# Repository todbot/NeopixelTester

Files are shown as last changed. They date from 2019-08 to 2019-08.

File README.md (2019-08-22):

# NeopixelTester

Some testing hardware for Neopixels (WS2812, SK6812)

In this repo:
- boards - schematic in Eagle format
- sketches - Sketches to run on Trinket M0

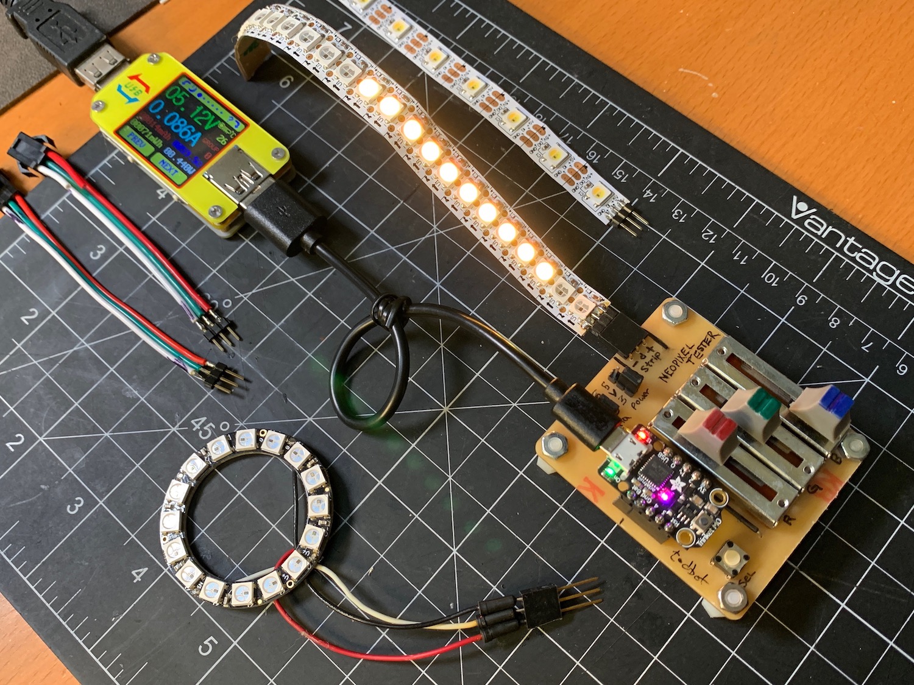
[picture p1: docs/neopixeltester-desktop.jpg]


## Video of how it works
Click the pic to watch the video
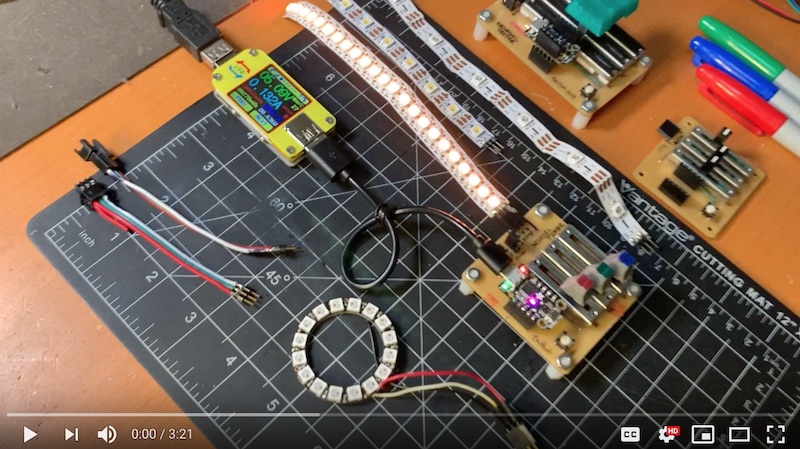
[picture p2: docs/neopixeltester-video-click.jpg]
Watch the video (https://youtu.be/KODPj4VacQQ)


## PCBs

Boards available on OSHPark:
https://oshpark.com/shared_projects/BqFE6DLx

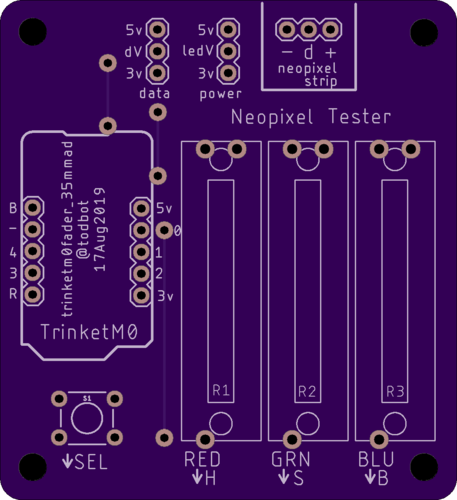
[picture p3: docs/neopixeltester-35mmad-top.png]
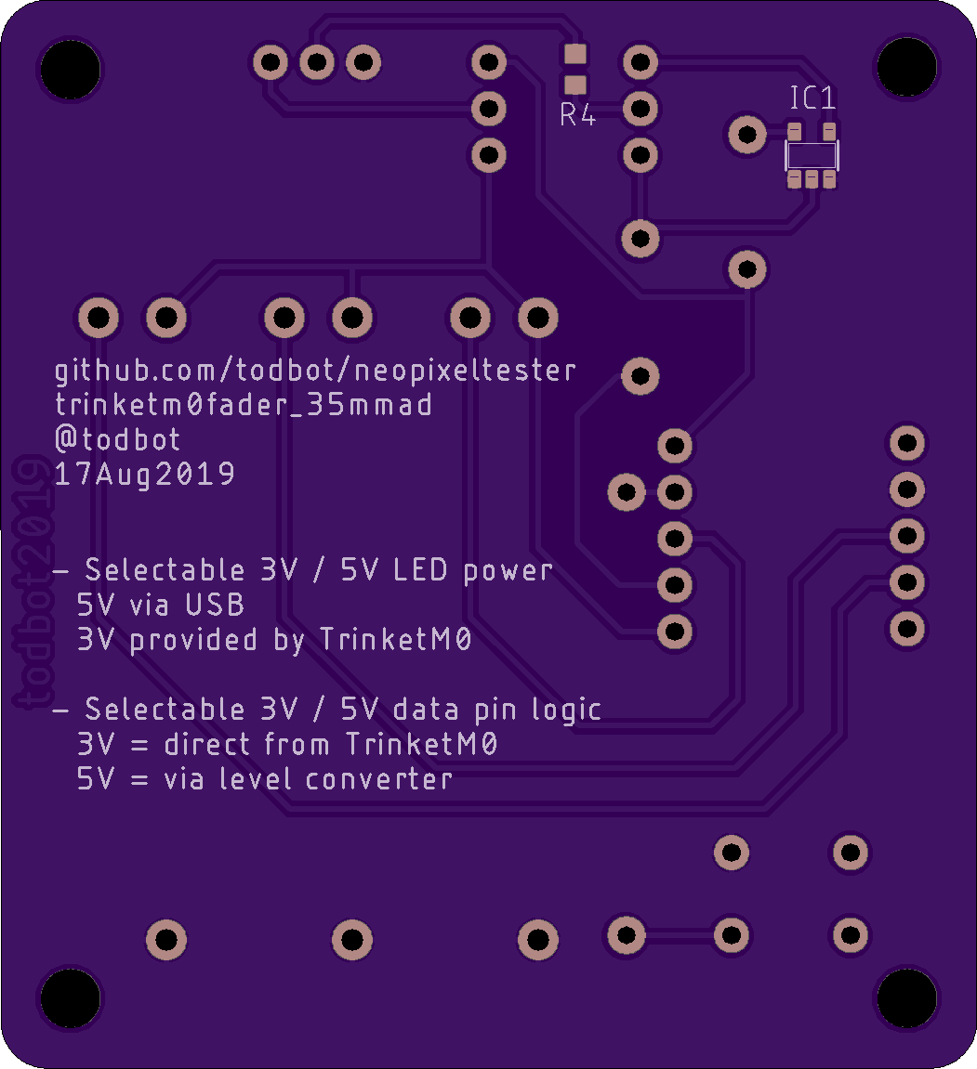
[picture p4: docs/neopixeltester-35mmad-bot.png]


Or you can mill your own with an Othermill/Bantam tools PCB mill. The board is designed to be single-sided milled with only three straight jumpers.

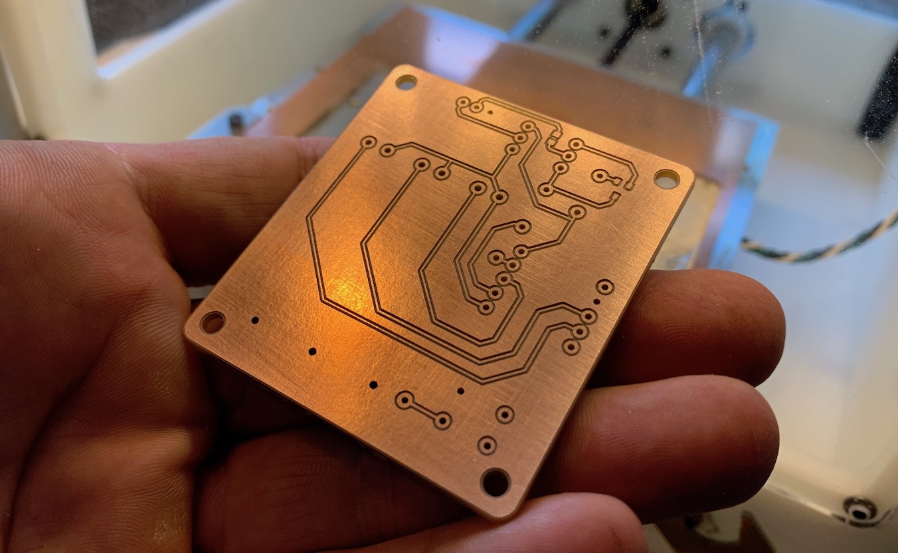
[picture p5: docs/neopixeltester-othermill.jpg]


## Bill of Materials
Bill of materials:
- Adafruit Trinket M0
- Adafruit 35mm slide pots x 3
- 74AHCT1G125DBV or SN74LV1T125DCKR level-shifter in SOT23-5 package
- 500 ohm resistor in 0603 package
- tact switch button
- male header pins, cut to length
- female header sockets, cut to length

Or if you're interested in the [60mm Amazon faders](http://amzn.com/B07PNDLKQQ?tag=todbotblog-20) on the other board.
And here's the [USB power meter](http://amzn.com/B07DK6FT4Q?tag=todbotblog-20) I showed in the video.

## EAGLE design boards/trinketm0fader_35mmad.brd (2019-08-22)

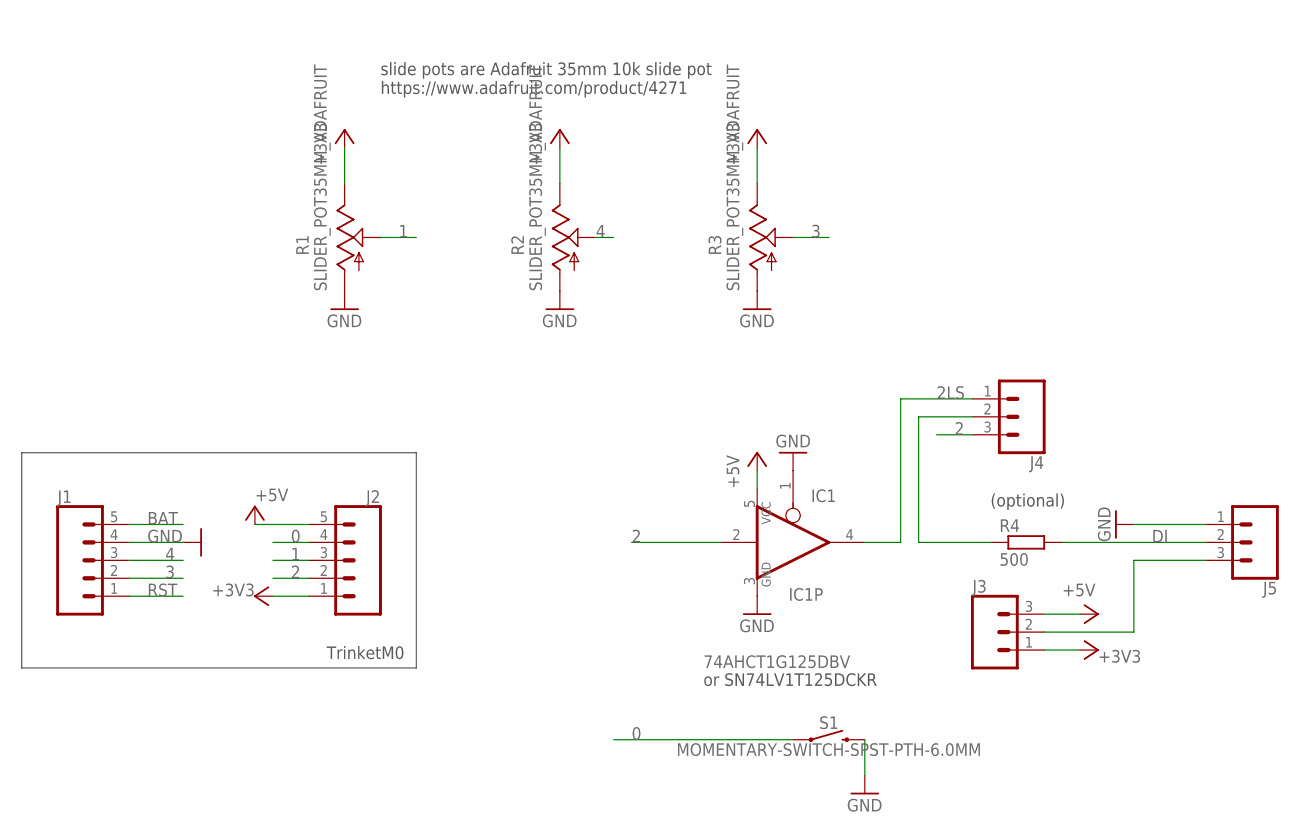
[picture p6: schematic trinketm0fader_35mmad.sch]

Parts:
IC1: 74AHCT1G125DBV; SOT23-5
J1, J2: CONN_05; 1X05
J3, J4, J5: CONN_03; 1X03
R1, R2, R3: SLIDER_POT35MM_ADAFRUIT; SLIDEPOD_35MM_ADAFRUIT
R4: 500; R0603
S1: MOMENTARY-SWITCH-SPST-PTH-6.0MM; TACTILE_SWITCH_PTH_6.0MM

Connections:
0: J2.4, S1.1
1: J2.3, R1.P$2 (W)
2: IC1.2 (I), J2.2, J4.3
2LS: IC1.4 (O), J4.1
3: J1.2, R3.P$2 (W)
4: J1.3, R2.P$2 (W)
+3V3: J2.1, J3.1, R1.P$1 (V), R2.P$1 (V), R3.P$1 (V)
+5V: IC1.5 (VCC), J2.5, J3.3
BAT: J1.5
DI: J5.2, R4.2
GND: IC1.1 (OE), IC1.3 (GND), J1.4, J5.1, R1.P$3 (G), R2.P$3 (G), R3.P$3 (G), S1.3 (2)
unnamed: J3.2, J5.3
unnamed: J4.2, R4.1
RST: J1.1

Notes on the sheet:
(optional)
TrinketM0
slide pots are Adafruit 35mm 10k slide pot https://www.adafruit.com/product/4271
or SN74LV1T125DCKR

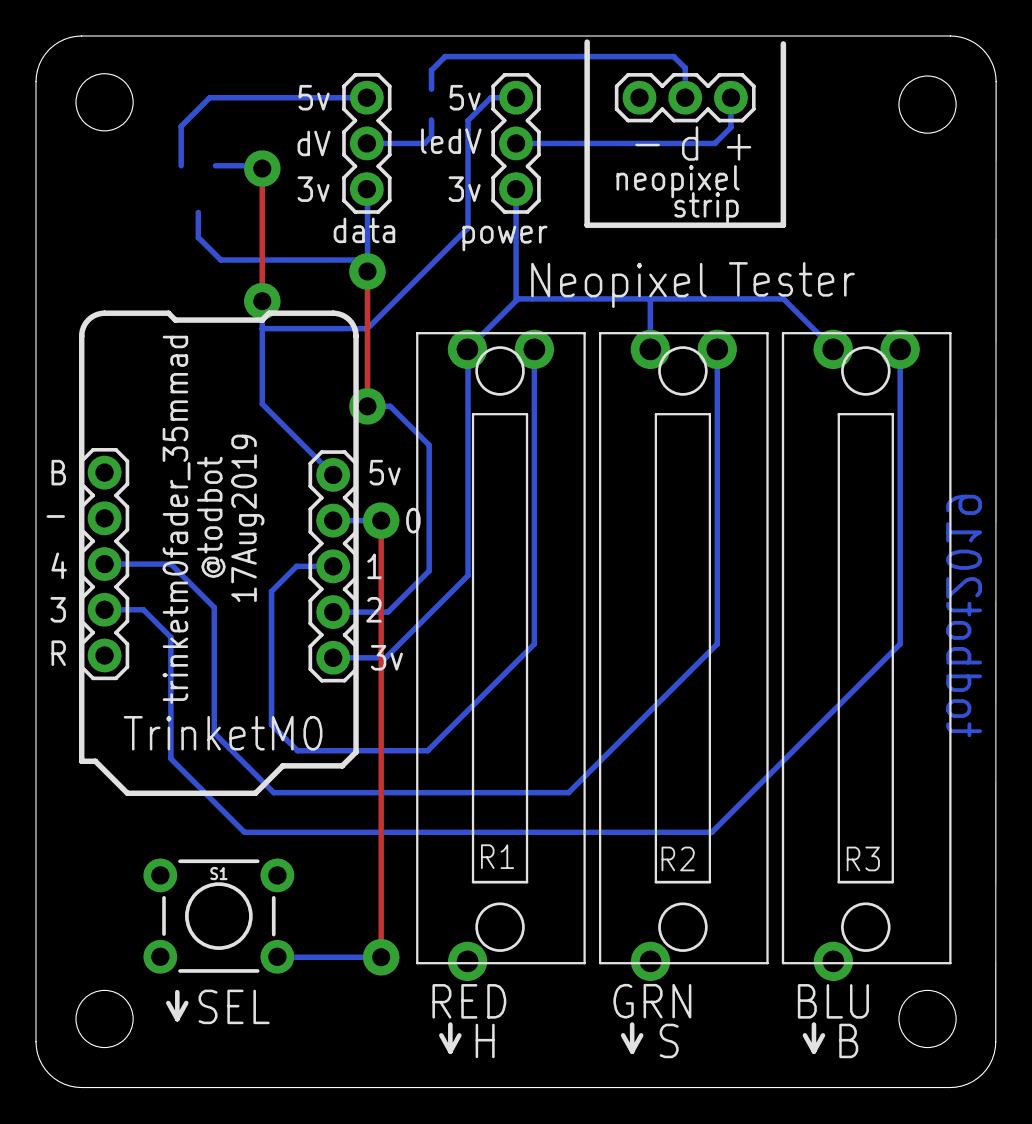
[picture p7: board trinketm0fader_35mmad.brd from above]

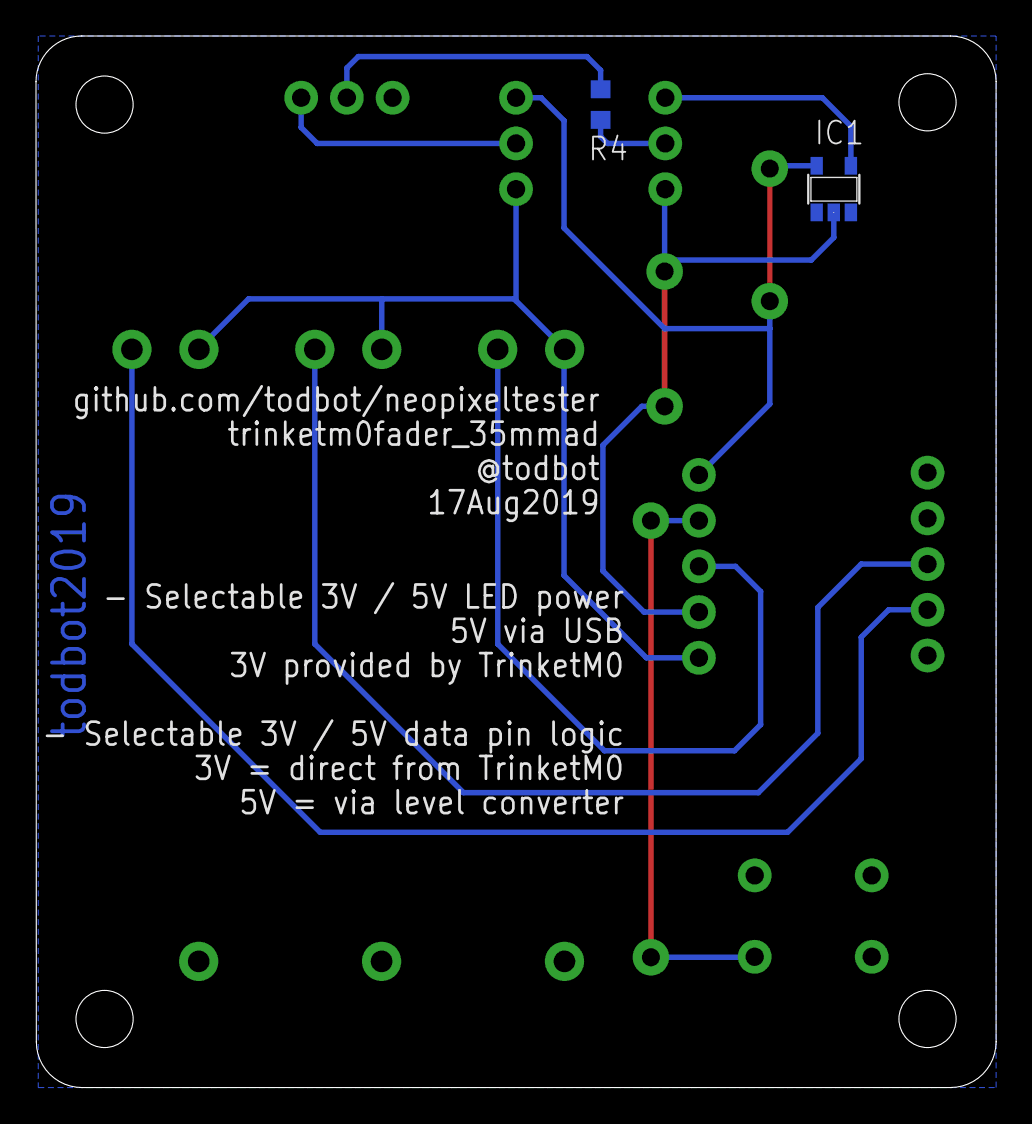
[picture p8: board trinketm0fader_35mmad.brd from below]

Board: 2 copper layers, 53.3 x 58.4 mm, 11 parts (2 on the bottom side), 12 nets.

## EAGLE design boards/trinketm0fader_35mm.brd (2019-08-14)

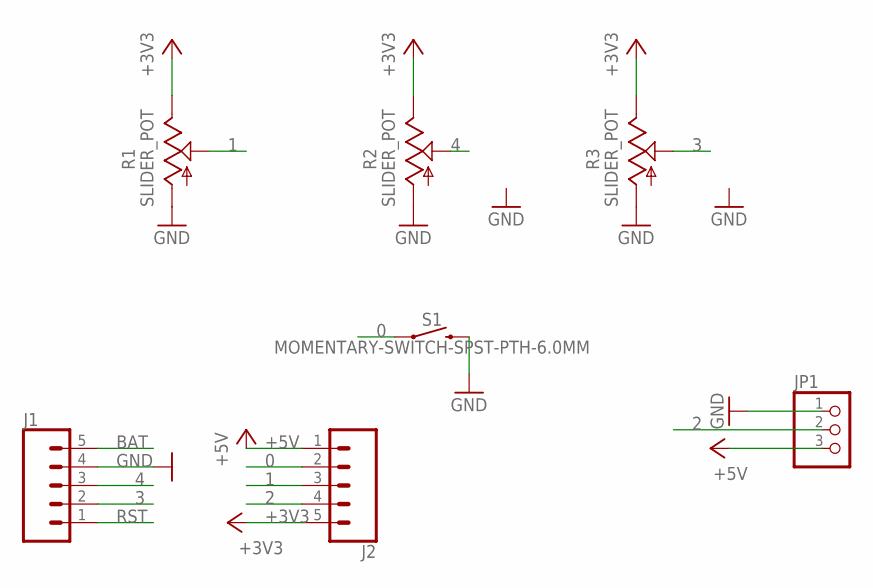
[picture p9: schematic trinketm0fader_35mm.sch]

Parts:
J1, J2: CONN_05; 1X05
JP1: PINHD-1X3; 1X03
R1, R2, R3: SLIDER_POT; SLIDEPOT_35MM_GUITAR
S1: MOMENTARY-SWITCH-SPST-PTH-6.0MM; TACTILE_SWITCH_PTH_6.0MM

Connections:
0: J2.2, S1.1
1: J2.3, R1.P$2 (S)
2: J2.4, JP1.2
3: J1.2, R3.P$2 (S)
4: J1.3, R2.P$2 (S)
+3V3: J2.5, R1.P$1 (E), R2.P$1 (E), R3.P$1 (E)
+5V: J2.1, JP1.3
BAT: J1.5
GND: J1.4, JP1.1, R1.P$4 (A), R2.P$4 (A), R3.P$4 (A), S1.3 (2)
RST: J1.1

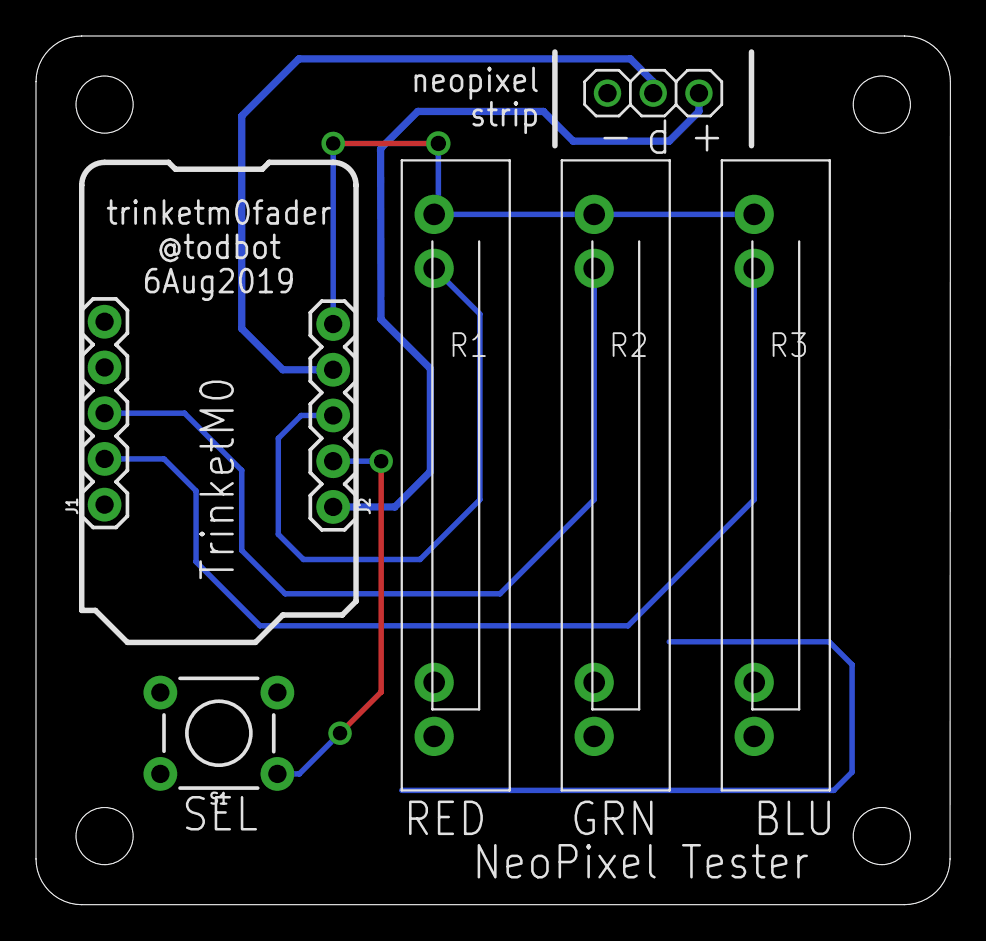
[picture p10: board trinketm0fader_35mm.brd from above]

Board: 2 copper layers, 50.8 x 48.3 mm, 7 parts (0 on the bottom side), 8 nets.

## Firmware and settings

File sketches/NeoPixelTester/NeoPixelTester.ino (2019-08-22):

/* NeoPixelTester 
 * ------------------- 
 * Simple Hello world for serial ports.
 * Print out "Hello world!" and blink pin 13 LED every second.
 *
 * Created 13 Aug 2019
 * 2019 Tod E. Kurt <tod@todbot.com>`http://todbot.com/
 */

#include <Adafruit_NeoPixel.h>
#include <Adafruit_DotStar.h>

//#define NUMPIXELS 16 // Popular NeoPixel ring size
#define NUMPIXELS 50 

// Pins in use
const int LED_PIN     = 13; // onboard LED
const int BUTT_PIN    = 0;  // D0 A2
const int NEO_PIN     = 2;  // D2 A1
const int SLIDER1_PIN = A0; // D1
const int SLIDER2_PIN = A4; // D4
const int SLIDER3_PIN = A3; // D3
const int DOTSTAR_DAT = 7; 
const int DOTSTAR_CLK = 8; 

Adafruit_DotStar dotstrip = Adafruit_DotStar( 1, DOTSTAR_DAT, DOTSTAR_CLK, DOTSTAR_BGR);

Adafruit_NeoPixel* pixels;

uint8_t r,g,b,w;
int startLed = 0;
int endLed = NUMPIXELS;
uint8_t brightness = 255;
uint32_t debugNextMillis;

bool rgbw_mode = false;

void setup() 
{
    dotstrip.begin(); // Initialize pins for output
    dotstrip.setPixelColor(0,0x003300);
    dotstrip.show();
    
    Serial.begin(115200);
    pinMode(LED_PIN, OUTPUT); 
    pinMode(SLIDER1_PIN, INPUT);
    pinMode(SLIDER2_PIN, INPUT);
    pinMode(SLIDER3_PIN, INPUT);
    pinMode(BUTT_PIN, INPUT_PULLUP);

    pixels = new Adafruit_NeoPixel(NUMPIXELS, NEO_PIN, NEO_GRB + NEO_KHZ800);
    pixels->begin();
    pixels->setBrightness(brightness);

    // set RGBW on startup
    if( digitalRead(BUTT_PIN) == LOW ) { 
        rgbw_mode = true;
        //pixels->updateType( NEO_RGBW );
        pixels = new Adafruit_NeoPixel(NUMPIXELS, NEO_PIN, NEO_GRBW + NEO_KHZ800);
    }
  
    // say hello
    for(int i=0; i<NUMPIXELS; i++) { 
        pixels->setPixelColor(i, pixels->Color(0, 150, 0));
        pixels->show();   // Send the updated pixel colors to the hardware.
        delay(30);
    }  
}

void loop () 
{
    digitalWrite(LED_PIN, HIGH);
    int v0 = digitalRead(BUTT_PIN);
    int v1 = analogRead(SLIDER1_PIN);
    int v2 = analogRead(SLIDER2_PIN);
    int v3 = analogRead(SLIDER3_PIN);
  
    // debug once every 100 millis
    if( debugNextMillis - millis() > 100 ) { 
        debugNextMillis = millis() + 100;
        Serial.printf("mode:rgb%c ins: %d, %d, %d, %d, st:%d end:%d bri:%d\n",
            (rgbw_mode?'w':' '), v0, v1,v2,v3, startLed, endLed, brightness);
    }
 
    if( v0 ) {  // normal mode: sliders are RGB
        dotstrip.setPixelColor(0,0x330033); // mode
        dotstrip.show();
        r = v1 / 4;
        g = v2 / 4;
        b = v3 / 4;
    }
    else {      // alt mode
        dotstrip.setPixelColor(0,0x333333);
        dotstrip.show();
        brightness = v3 / 4;
        startLed = map( v1, 0,1023, 0,NUMPIXELS-1);
        int numLeds = map( v2, 0,1023, 1,NUMPIXELS);
        endLed = startLed + numLeds;
        if( endLed > NUMPIXELS ) { 
            endLed = NUMPIXELS;       
        }
        pixels->setBrightness(brightness);
    }

    pixels->clear();
    for(int i=startLed; i<endLed; i++) { 
        pixels->setPixelColor(i, pixels->Color(r,g,b));
    }
    pixels->show();
  
    digitalWrite(LED_PIN, LOW);
}

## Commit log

2019-08-19 added adafruit fader version
    [trinketm0fader_35mmad.brd, trinketm0fader_35mmad.sch]
2019-08-22 quicky bom

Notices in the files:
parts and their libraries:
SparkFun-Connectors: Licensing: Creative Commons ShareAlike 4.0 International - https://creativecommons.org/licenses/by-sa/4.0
